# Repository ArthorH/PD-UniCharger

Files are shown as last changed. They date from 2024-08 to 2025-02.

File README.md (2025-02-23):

rect14220

# Universal Type C charger for every battery type !

obraz

## Key technologies:
 &nbsp;&nbsp;&nbsp;&nbsp; &nbsp;&nbsp;&nbsp;&nbsp;
---
# Features
- CC CV regulation
- Multiple settings
- USB C power delivery 20v
- Reverse polarity battery protection
---
# BLOCK DIAGRAM
Untitled Diagram(3) drawio(1)

# How it works:
## IP2721
IP2721 negotiates voltage set by J2 (short 20v open 15v) and outputs it to VBUS_PD

<p float="left">
  
   
</p>

## CC CV Stepdown
Typycal LM358 based CC CV regulation circuit
<p float="left">
  
   
</p>

### CC CV in operation
CC            |  CV
:-------------------------:|:-------------------------:
  |   

## Battery reverse polarity protection 
Battery protection circuit works as SR latch with one of latching elements being P-MOS that outputs voltage to battery.
One downside to using this schematic is that charger needs to be powered down in order to "delatch" protection circuit, otherwise it may not work if battery had been disconected and reconnected again. This issue will be fixed in upcomming REV-B. 
<p float="left">
  
   
</p>

### How it works
#### Phase 1
Power on state. Circuit is delatched. 

Ukł_zabiezpieczający_OFF

#### Phase 2
Connected battery starts to turn on transistor that turns on photocoupler. Circuit latches and starts charging battery, given it can provide 20ma of current and it sits above 1.5v.

Ukł_zabiezpieczający_ON

## Usage
Intended use is keychain charger to charge for example car battery form powerbank that is capable of PD output.

obraz

It is advantageous to carry a portable charging board in a vehicle or backpack as a contingency, even though its charging efficiency may not be optimal.

# License 
CERN-OHL-P
(CERN Open Hardware Licence Version 2 - Permissive)

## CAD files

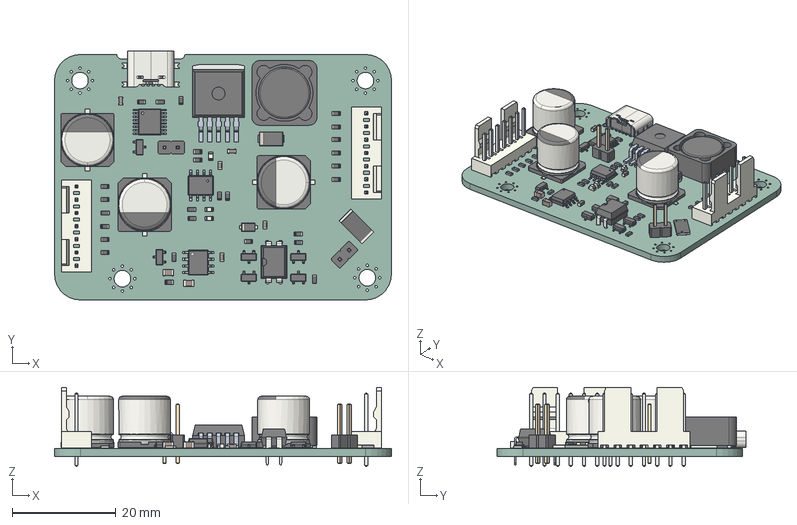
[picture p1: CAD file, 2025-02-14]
Mechanical/UniCharger.step
64.9 x 48.0 x 15.3 mm
CQ assembly x 2
R_0603_1608Metric x 27
LED_0603_1608Metric x 3
CP_Elec_10x10 x 3
DIP-4_W7.62mm
Molex_AE_6410_07A x 2
SOT_23 x 6
C_0805_2012Metric x 2
USB_C_Receptacle_6P_TopMnt_Horizontal_GCT_USB4135-GF-A
SOIC_8_39x49mm_P127mm
PinHeader_1x02_P254mm_Vertical x 2
R_2512_6332Metric
C_0603_1608Metric x 5
D_SOD_123F
TSSOP_16_44x5mm_P065mm
SRR1260
D_SMA
_autosave-Universal_battery_charger_PCB

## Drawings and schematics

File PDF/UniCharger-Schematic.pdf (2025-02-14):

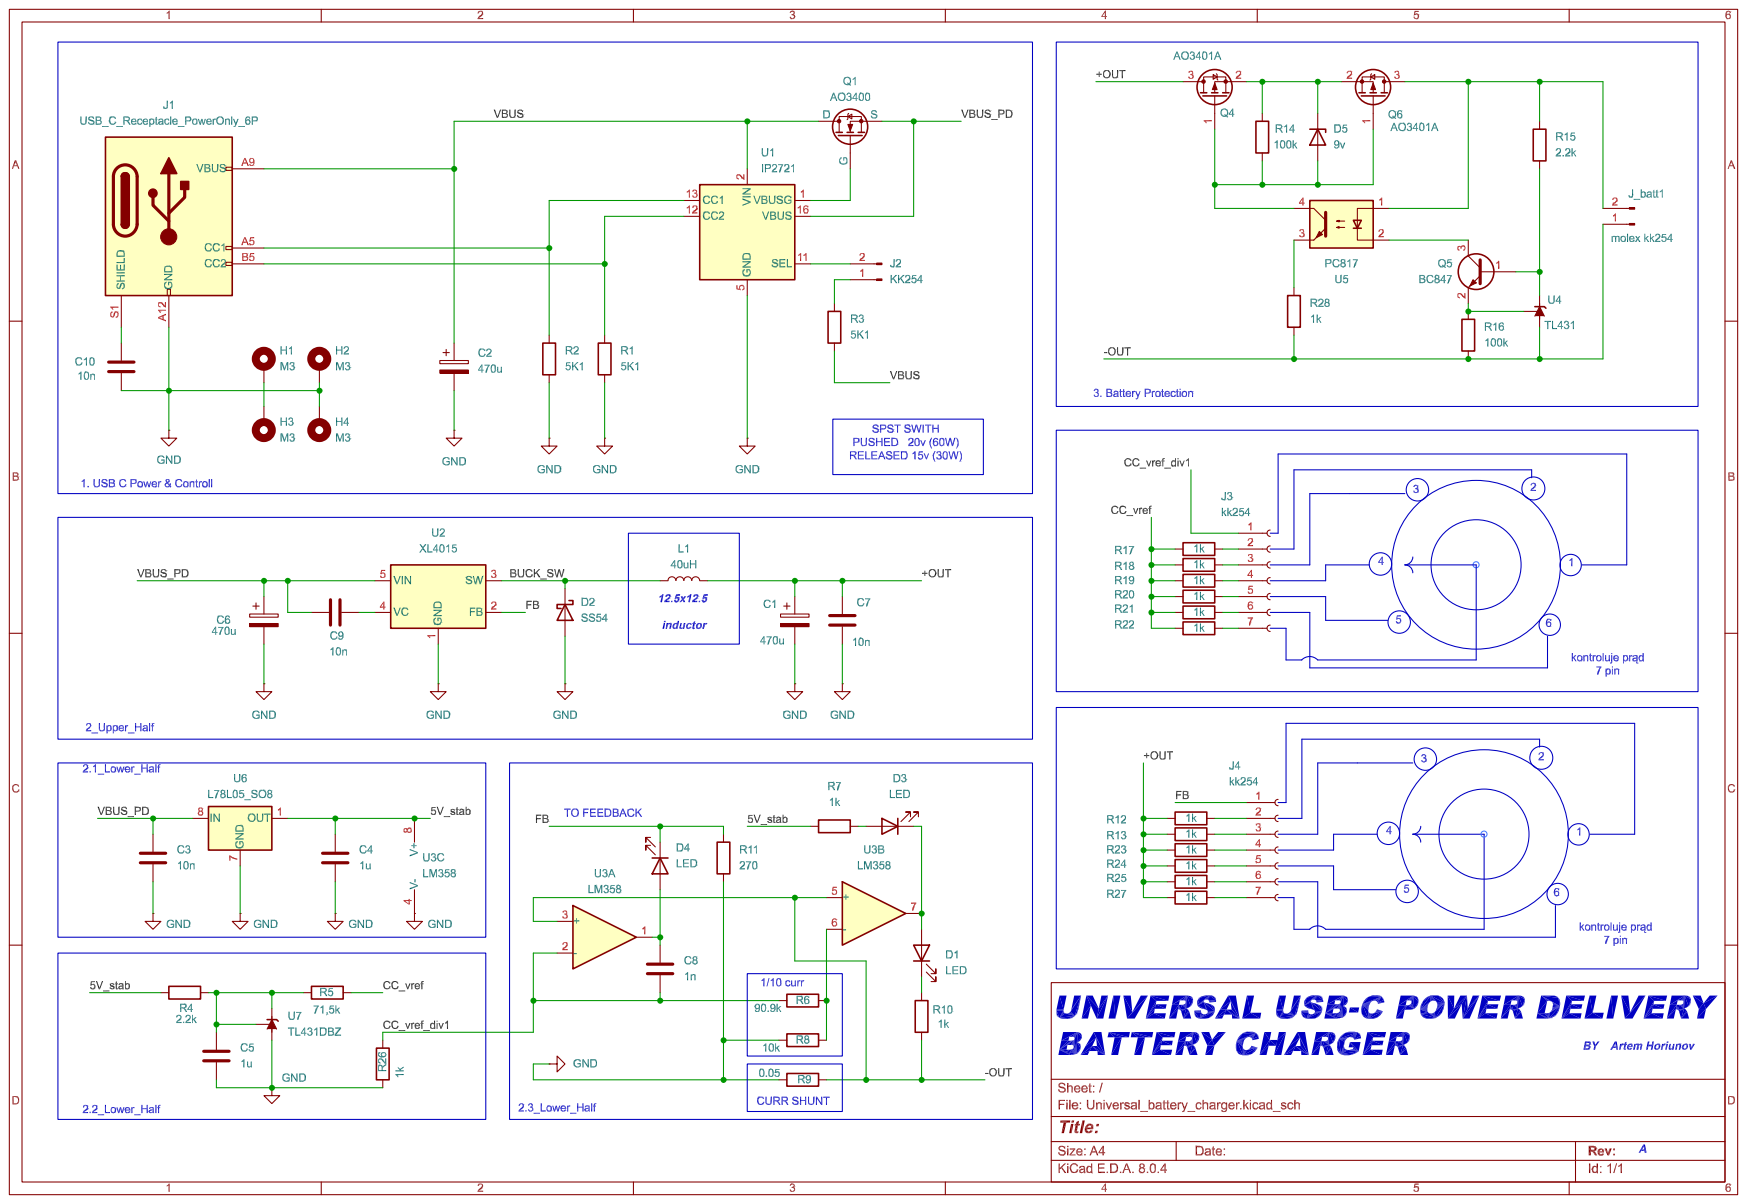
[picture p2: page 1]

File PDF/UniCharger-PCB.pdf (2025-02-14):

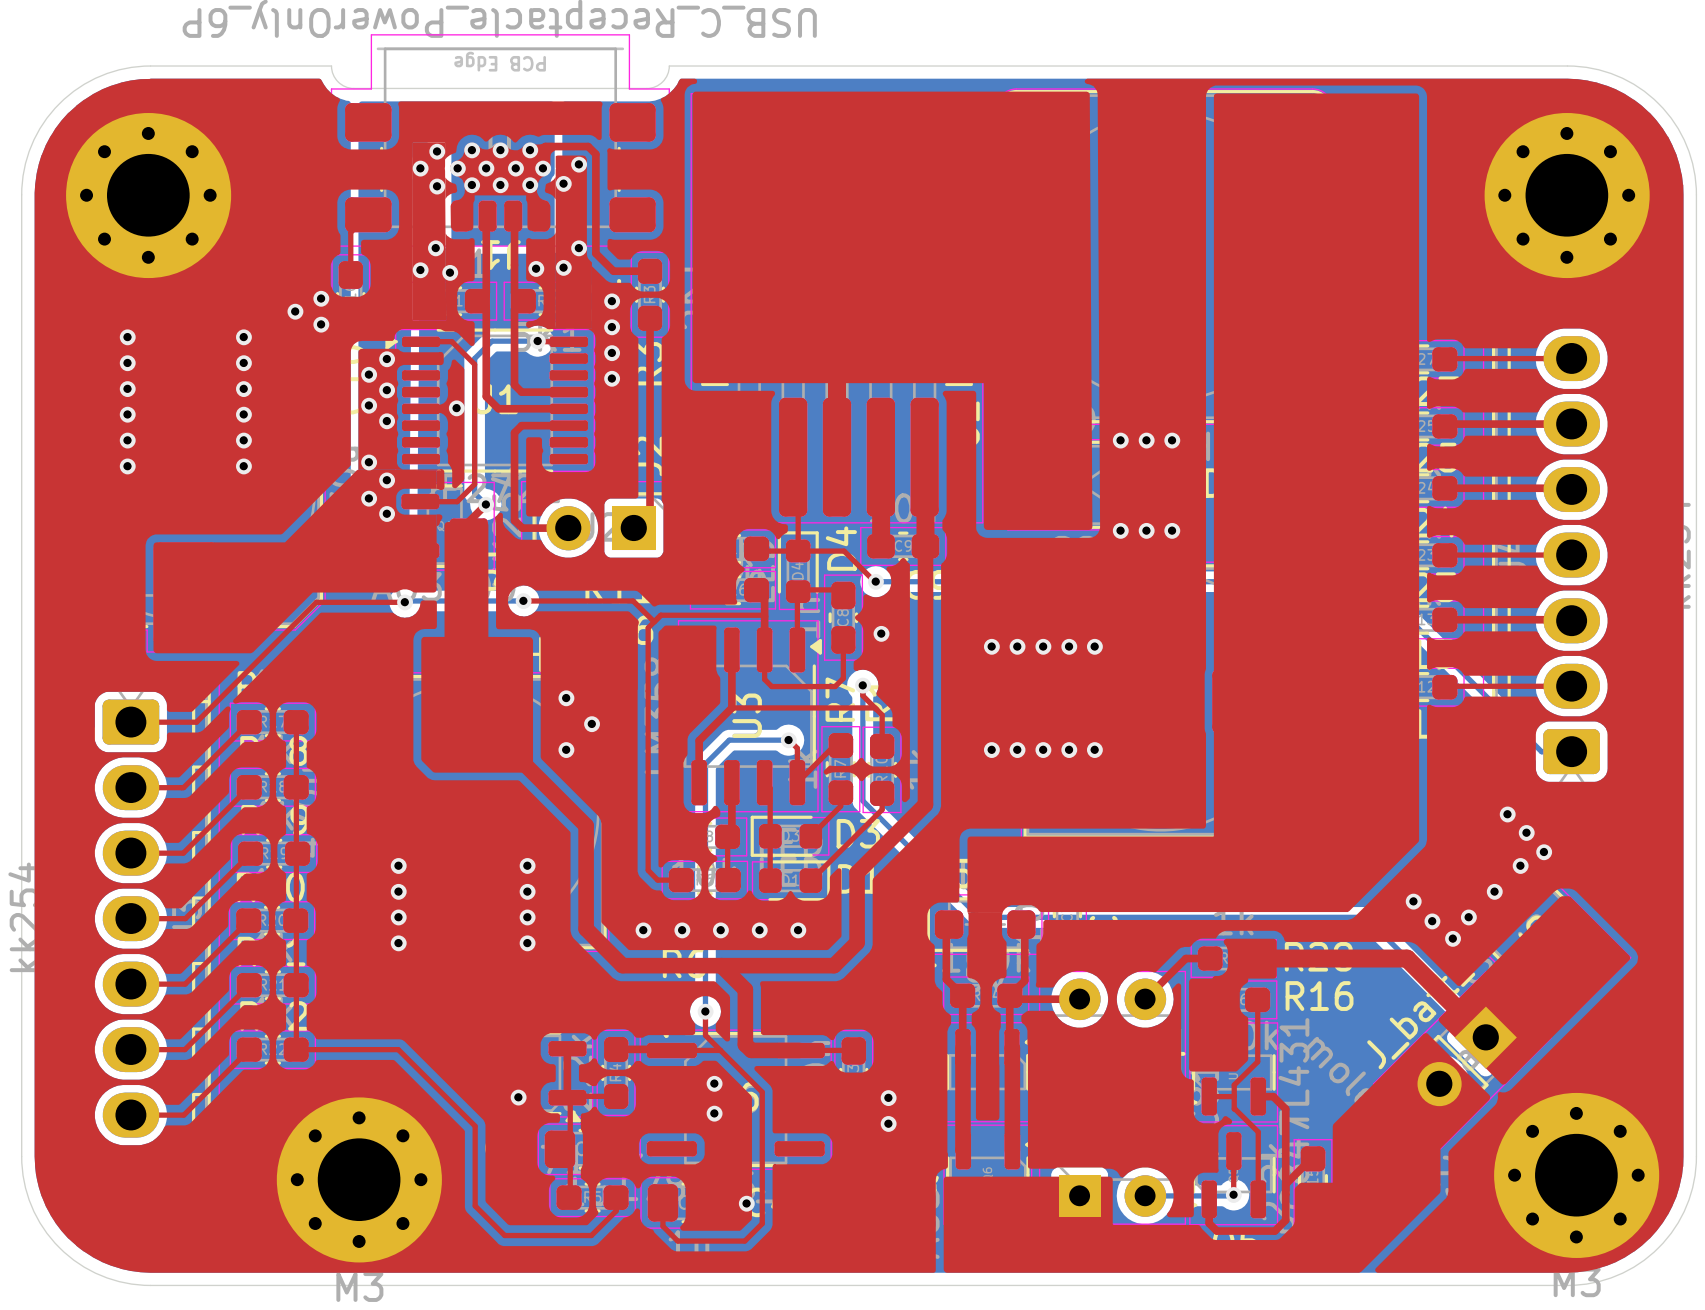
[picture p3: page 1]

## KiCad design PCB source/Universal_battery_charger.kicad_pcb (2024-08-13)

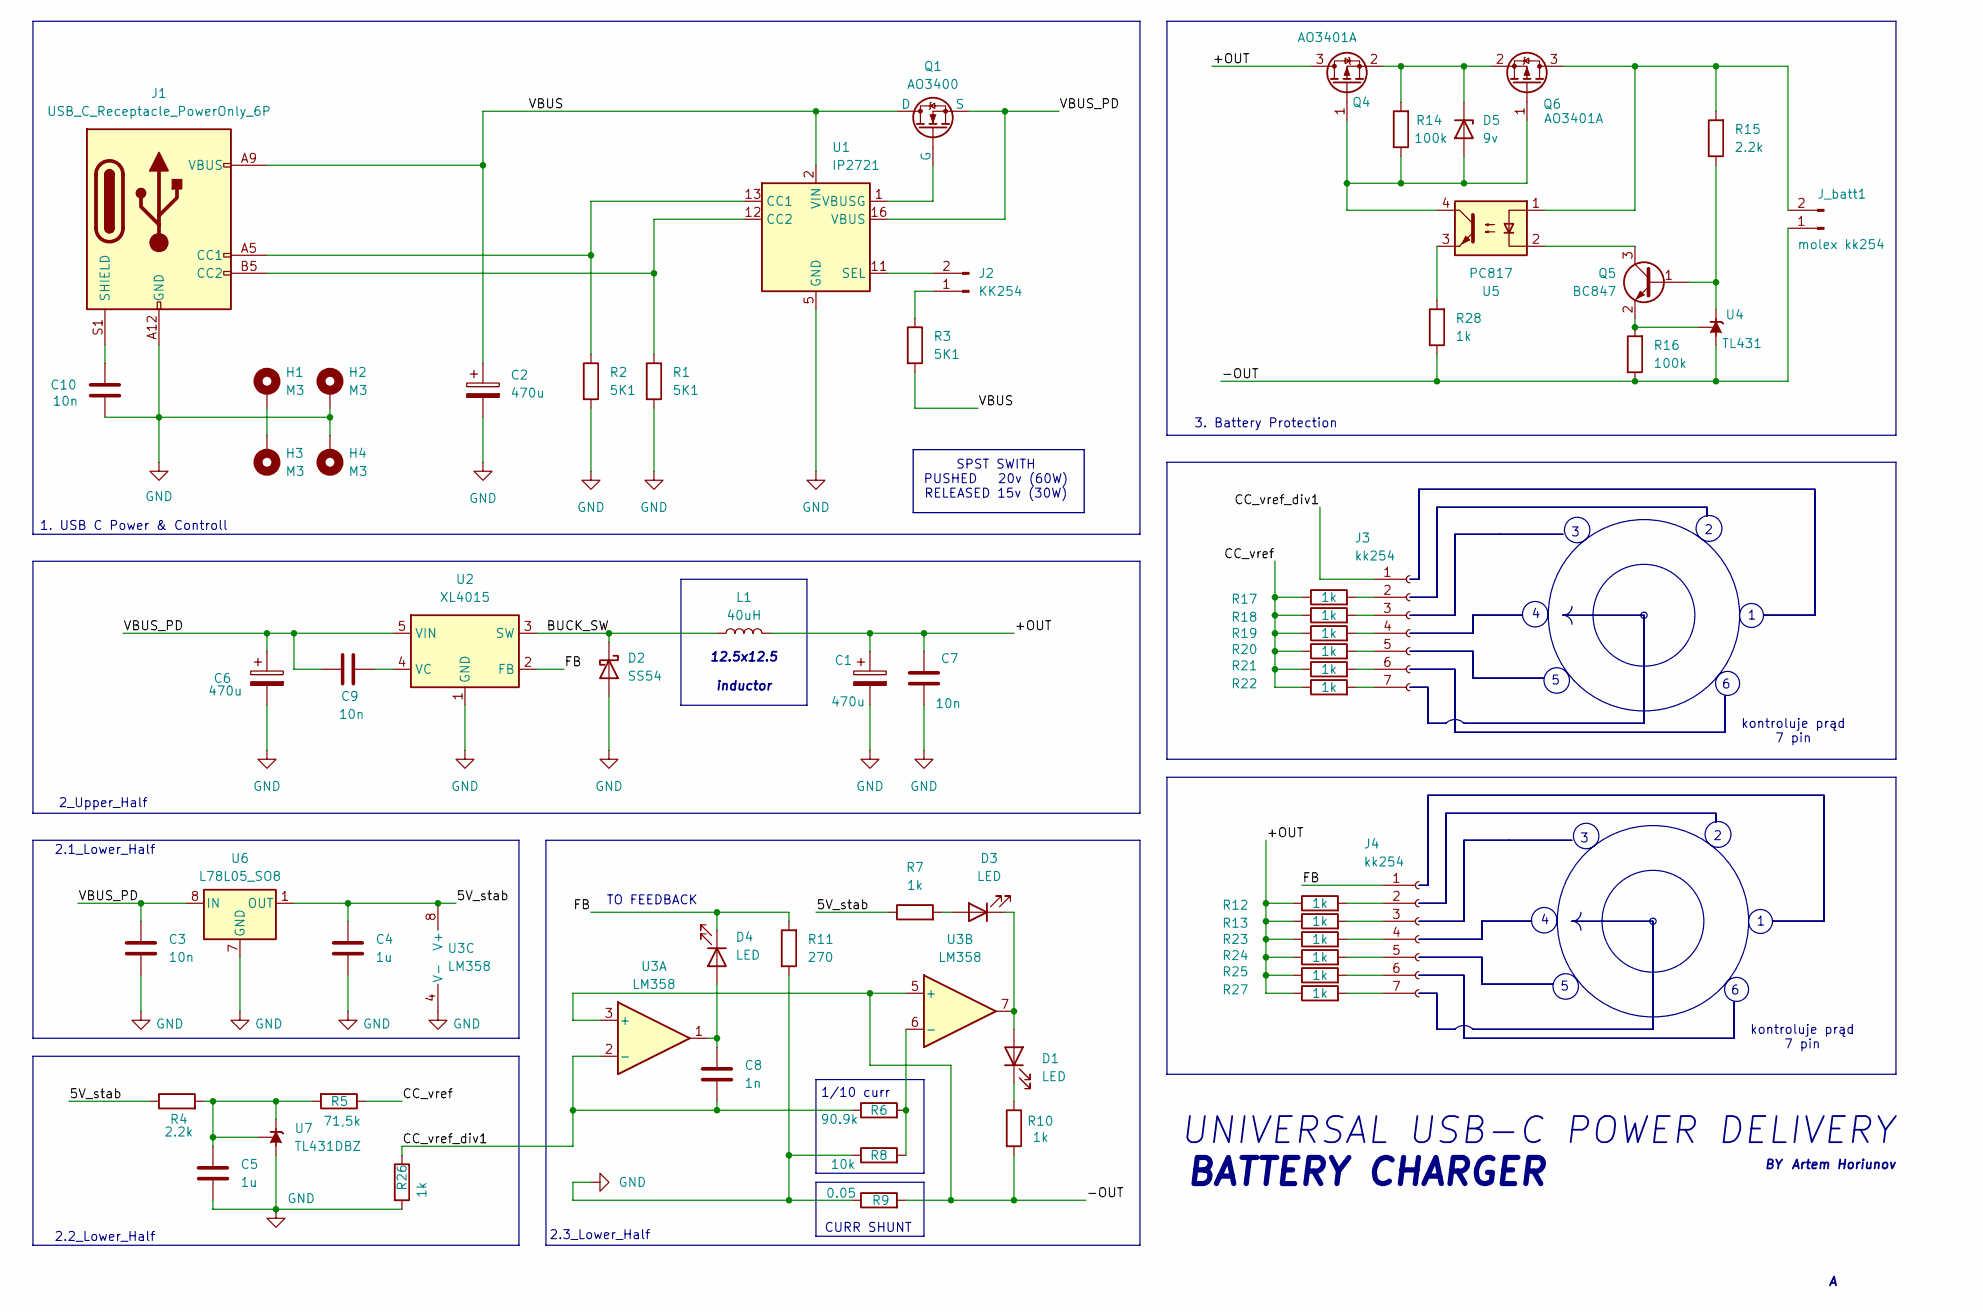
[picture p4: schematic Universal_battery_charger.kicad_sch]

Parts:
C1, C2, C6: 470u; CP_Elec_10x10
C3, C7, C9, C10: 10n; C_0603_1608Metric_Pad1.08x0.95mm_HandSolder
C4, C5: 1u; C_0805_2012Metric_Pad1.18x1.45mm_HandSolder
C8: 1n; C_0603_1608Metric_Pad1.08x0.95mm_HandSolder
D1, D3, D4: LED; LED_0603_1608Metric
D2: SS54; D_SMA
D5: 9v; D_SOD-123F
H1, H2, H3, H4: M3; MountingHole_3.2mm_M3_Pad_Via
J1: USB_C_Receptacle_PowerOnly_6P; USB_C_Receptacle_GCT_USB4135-GF-A_6P_TopMnt_Horizontal
J2: KK254; PinHeader_1x02_P2.54mm_Vertical
J3, J4: kk254; Molex_KK-254_AE-6410-07A_1x07_P2.54mm_Vertical
J_batt1: molex kk254; PinHeader_1x02_P2.54mm_Vertical
L1: 40uH; L_Bourns_SRR1260
Q1: AO3400; SOT-23
Q4, Q6: AO3401A; SOT-23
Q5: BC847; SOT-23
R1, R2, R3: 5K1; R_0603_1608Metric_Pad0.98x0.95mm_HandSolder
R4, R15: 2.2k; R_0603_1608Metric_Pad0.98x0.95mm_HandSolder
R5: 71,5k; R_0603_1608Metric_Pad0.98x0.95mm_HandSolder
R6: 90.9k; R_0603_1608Metric_Pad0.98x0.95mm_HandSolder
R7, R10, R12, R13, R17, R18, R19, R20, R21, R22, R23, R24, R25, R26, R27, R28: 1k; R_0603_1608Metric_Pad0.98x0.95mm_HandSolder
R8: 10k; R_0603_1608Metric_Pad0.98x0.95mm_HandSolder
R9: 0.05; R_2512_6332Metric_Pad1.40x3.35mm_HandSolder
R11: 270; R_0603_1608Metric_Pad0.98x0.95mm_HandSolder
R14, R16: 100k; R_0603_1608Metric_Pad0.98x0.95mm_HandSolder
U1: IP2721; TSSOP-16_4.4x5mm_P0.65mm
U2: XL4015; TO-263-5_TabPin3
U3: LM358; SO-8_3.9x4.9mm_P1.27mm
U4: TL431; SOT-23
U5: PC817; DIP-4_W7.62mm
U6: L78L05_SO8; SOIC-8_3.9x4.9mm_P1.27mm
U7: TL431DBZ; SOT-23

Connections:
/5V_stab: C4.1, R4.1, R7.1, U3.8 (V+), U6.1 (OUT)
/+OUT: C1.1, C7.1, L1.2, Q4.3 (D), R12.1, R13.1, R23.1, R24.1, R25.1, R27.1
/-OUT: J_batt1.1, R9.2, R10.2, R16.1, R28.1, U3.3 (+), U3.5 (+), U4.3 (A)
/BUCK_SW: D2.1 (K), L1.1, U2.3 (SW)
/CC_vref: R5.1, R17.1, R18.1, R19.1, R20.1, R21.1, R22.1
/CC_vref_div1: C8.2, J3.1, R6.1, R26.1, U3.2 (-)
/FB: D4.1 (K), J4.1, R11.2, U2.2 (FB)
/VBUS: C2.1, J1.A9 (VBUS), J1.B9 (VBUS), Q1.2 (D), R3.2, U1.2 (VIN)
/VBUS_PD: C3.1, C6.1, C9.1, Q1.3 (S), U1.16 (VBUS), U2.5 (VIN), U6.8 (IN)
unnamed: D1.2 (A), D3.1 (K), U3.7
unnamed: D1.1 (K), R10.1
unnamed: D3.2 (A), R7.2
unnamed: C8.1, D4.2 (A), U3.1
unnamed: D5.2 (A), Q4.1 (G), Q6.1 (G), R14.1, U5.4
unnamed: D5.1 (K), Q4.2 (S), Q6.2 (S), R14.2
unnamed: J1.A5 (CC1), R2.1, U1.13 (CC1)
unnamed: J1.B5 (CC2), R1.1, U1.12 (CC2)
unnamed: C10.2, J1.S1 (SHIELD)
unnamed: J2.1, R3.1
unnamed: J2.2, U1.11 (SEL)
unnamed: J3.2, R17.2
unnamed: J3.3, R18.2
unnamed: J3.4, R19.2
unnamed: J3.5, R20.2
unnamed: J3.6, R21.2
unnamed: J3.7, R22.2
unnamed: J4.2, R12.2
unnamed: J4.3, R13.2
unnamed: J4.4, R23.2
unnamed: J4.5, R24.2
unnamed: J4.6, R25.2
unnamed: J4.7, R27.2
unnamed: J_batt1.2, Q6.3 (D), R15.2, U5.1
unnamed: Q1.1 (G), U1.1 (VBUSG)
unnamed: Q5.1 (B), R15.1, U4.2 (K)
unnamed: Q5.3 (C), U5.2
unnamed: Q5.2 (E), R16.2, U4.1 (REF)
unnamed: R28.2, U5.3
unnamed: C9.2, U2.4 (VC)
unnamed: R6.2, R8.2, U3.6 (-)
unnamed: C5.1, R4.2, R5.2, U7.1 (REF), U7.2 (K)

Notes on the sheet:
BATTERY CHARGER
1/10 curr
2.2_Lower_Half
TO FEEDBACK
kontroluje prąd 7 pin
2.1_Lower_Half
SPST SWITH PUSHED 20v (60W) RELEASED 15v (30W)
UNIVERSAL USB-C POWER DELIVERY
3. Battery Protection
2.3_Lower_Half
CURR SHUNT
12.5x12.5 inductor
1. USB C Power & Controll
2_Upper_Half
Artem Horiunov

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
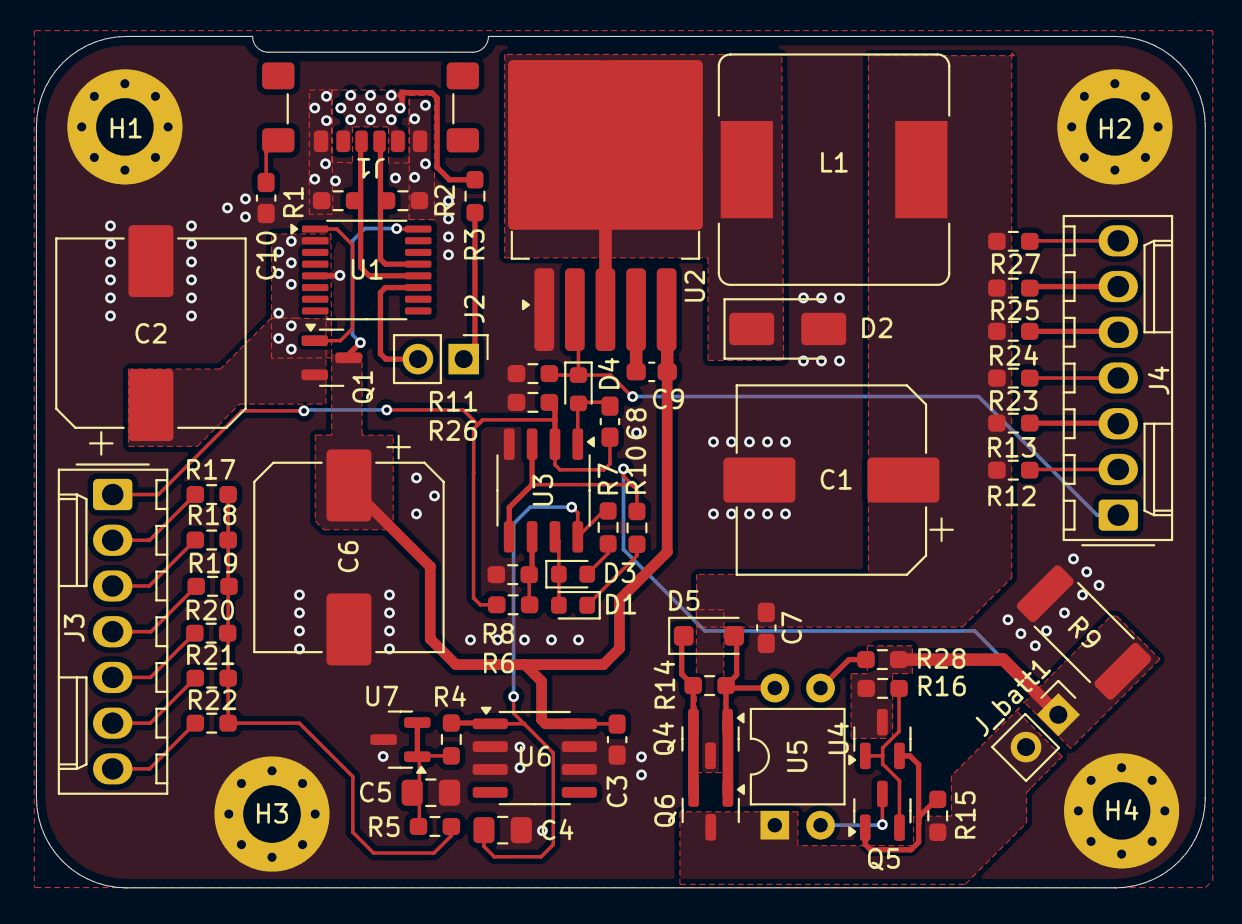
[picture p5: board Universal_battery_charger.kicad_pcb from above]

Board: 2 copper layers, 64.9 x 47.3 mm, 64 parts (0 on the bottom side), 42 nets.

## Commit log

2024-08-13 REV A
    [Universal_battery_charger.kicad_pcb, Universal_battery_charger.kicad_sch]
2025-02-14 Do Cleanup
    [UniCharger.step, Universal_battery_charger.kicad_pcb, Universal_battery_charger.kicad_sch]
